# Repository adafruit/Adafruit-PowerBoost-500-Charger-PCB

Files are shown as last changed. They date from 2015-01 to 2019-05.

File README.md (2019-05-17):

# Adafruit PowerBoost 500 Charger PCB
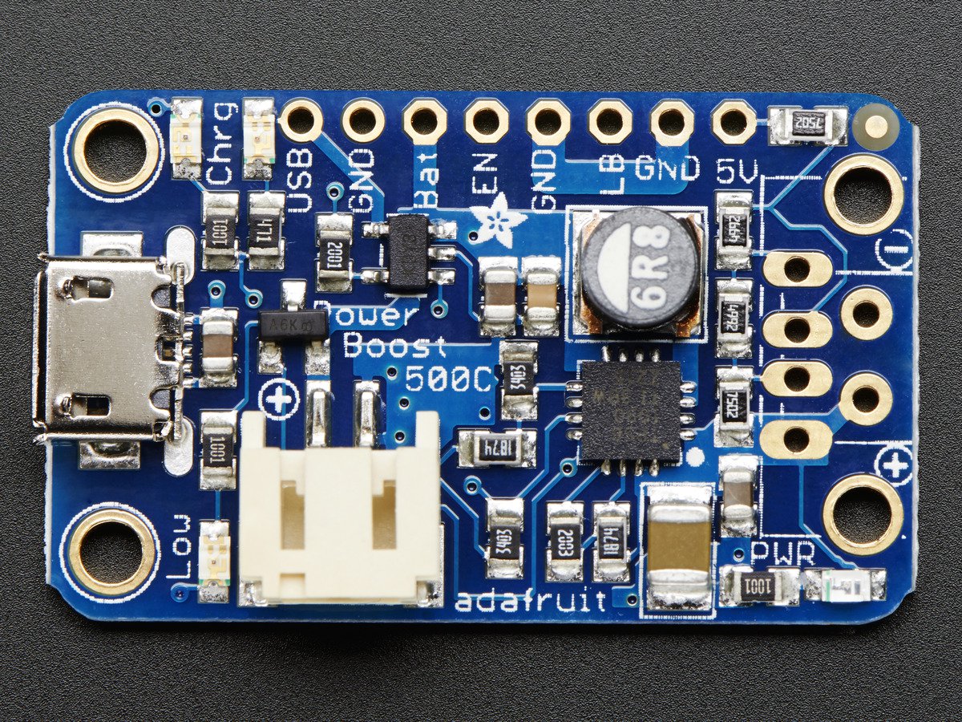
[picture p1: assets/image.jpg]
<a href="http://www.adafruit.com/products/1944"><br/>
Click here to purchase one from the Adafruit shop
</a>

The PowerBoost 500C is the perfect power supply for your portable project! With a built-in battery charger circuit, you'll be able to keep your project running even while recharging the battery! This little DC/DC boost converter module can be powered by any 3.7V LiIon/LiPoly battery, and convert the battery output to 5.2V DC for running your 5V projects.

Like our popular 5V 1A USB wall adapter, the output has been tweaked to be 5.2V instead of a straight-up 5.0V so that there's a little bit of 'headroom' for long cables, high draw, the addition of a diode on the output if you wish, etc. The 5.2V is safe for all 5V-powered electronics like Arduino, Adafruit Metro, Raspberry Pi, or BeagleBone while preventing icky brown-outs during high current draw because of USB cable resistance.

The PowerBoost 500C has at the heart a TPS61090 boost converter from TI. This boost converter chip has some really nice extras such as low battery detection, 2A internal switch, synchronous conversion, excellent efficiency, and 700KHz high-frequency operation.

This repo contains the PCB files for the Adafruit PowerBoost 500 Charger

### License

Adafruit invests time and resources providing this open source design, please support Adafruit and open-source hardware by purchasing products from [Adafruit](https://www.adafruit.com)!

All text above must be included in any redistribution

Designed by Limor Fried/Ladyada for Adafruit Industries.
Creative Commons Attribution/Share-Alike, all text above must be included in any redistribution. 
See license.txt for additional information.

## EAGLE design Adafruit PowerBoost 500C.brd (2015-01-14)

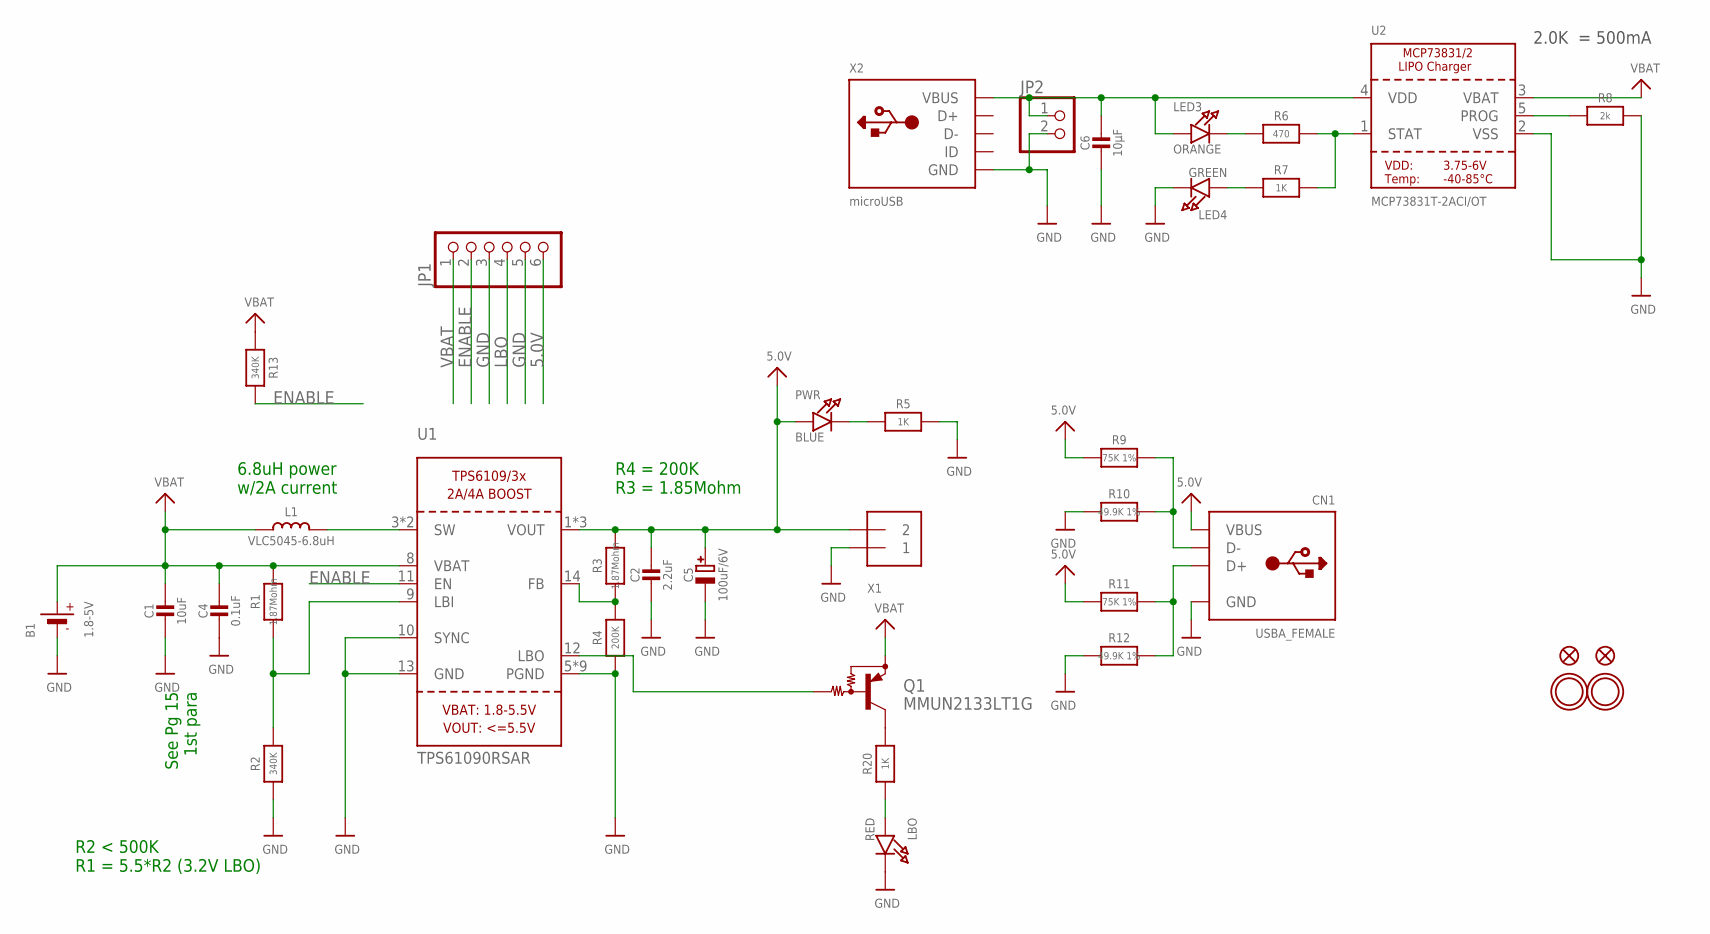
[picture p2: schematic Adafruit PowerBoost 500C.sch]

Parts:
B1: 1.8-5V; JSTPH2
C1: 10uF; 0805-NO
C2: 2.2uF; 0805-NO
C4: 0.1uF; 0805-NO
C5: 100uF/6V; EIA3528-21/B-R
C6: 10µF; 0805-NO
CN1: USBA_FEMALE; USB_HOST-PTH
FID2, FID3: FIDUCIAL""; FIDUCIAL_1MM
JP1: PINHD-1X6CB; 1X06-CLEANBIG
JP2: HEADER-1X2ROUND; 1X02_ROUND
L1: VLC5045-6.8uH; INDUCTOR_5X5MM_TDK_VLC5045
LBO: RED; CHIPLED_0805_NOOUTLINE
LED3: ORANGE; CHIPLED_0805_NOOUTLINE
LED4: GREEN; CHIPLED_0805_NOOUTLINE
PWR: BLUE; CHIPLED_0805_NOOUTLINE
Q1: MMUN2133LT1G; SC59-BEC
R1, R3: 1.87Mohm; 0805-NO
R2, R13: 340K; 0805-NO
R4: 200K; 0805-NO
R5, R7, R20: 1K; 0805-NO
R6: 470; 0805-NO
R8: 2k; 0805-NO
R9, R11: 75K 1%; 0805-NO
R10, R12: 49.9K 1%; 0805-NO
U1: TPS61090RSAR; PVQFN-16
U2: MCP73831T-2ACI/OT; SOT23-5
U$10, U$12: MOUNTINGHOLE2.5; MOUNTINGHOLE_2.5_PLATED
X1: TERMBLOCK_1X2; TERMBLOCK_1X2-3.5MM
X2: microUSB; 4UCONN_20329

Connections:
5.0V: C2.1, C5.+, CN1.VBUS, JP1.6, PWR.A, R3.2, R9.2, R11.2, U1.1 (VOUT), U1.15 (VOUT), U1.16 (VOUT), X1.2
D+: CN1.D+, R11.1, R12.1
D-: CN1.D-, R9.1, R10.1
ENABLE: JP1.2, R13.2, U1.11 (EN)
GND: B1.1 (-), C1.2, C2.2, C4.2, C5.-, C6.2, CN1.GND, JP1.3, JP1.5, JP2.2, LBO.C, LED4.C, R2.1, R4.1, R5.2, R8.2, R10.2, R12.2, U1.5 (PGND), U1.6 (PGND), U1.7 (PGND), U1.10 (SYNC), U1.13 (GND), U1.P$18 (PGND), U1.P$19 (PGND), U1.P$20 (PGND), U1.P$21 (PGND), U1.P$22 (PGND), U1.THERMAL (PGND), U2.2 (VSS), X1.1, X2.BASE@1 (GND), X2.BASE@2 (GND), X2.GND, X2.SPRT@1 (GND), X2.SPRT@2 (GND), X2.SPRT@3 (GND), X2.SPRT@4 (GND)
LBO: JP1.4, Q1.B, U1.12 (LBO)
unnamed: L1.P$2 (2), U1.3 (SW), U1.4 (SW)
unnamed: LBO.A, R20.1
unnamed: R1.1, R2.2, U1.9 (LBI)
unnamed: PWR.C, R5.1
unnamed: R3.1, R4.2, U1.14 (FB)
unnamed: LED3.C, R6.1
unnamed: R6.2, R7.2, U2.1 (STAT)
unnamed: R8.1, U2.5 (PROG)
unnamed: LED4.A, R7.1
unnamed: Q1.C, R20.2
VBAT: B1.2 (+), C1.1, C4.1, JP1.1, L1.P$1 (1), Q1.E, R1.2, R13.1, U1.8 (VBAT), U2.3 (VBAT)
VDD1: C6.1, JP2.1, LED3.A, U2.4 (VDD), X2.VBUS

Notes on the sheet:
See Pg 15 1st para
6.8uH power w/2A current
R2 < 500K R1 = 5.5*R2 (3.2V LBO)
R4 = 200K R3 = 1.85Mohm
2.0K = 500mA

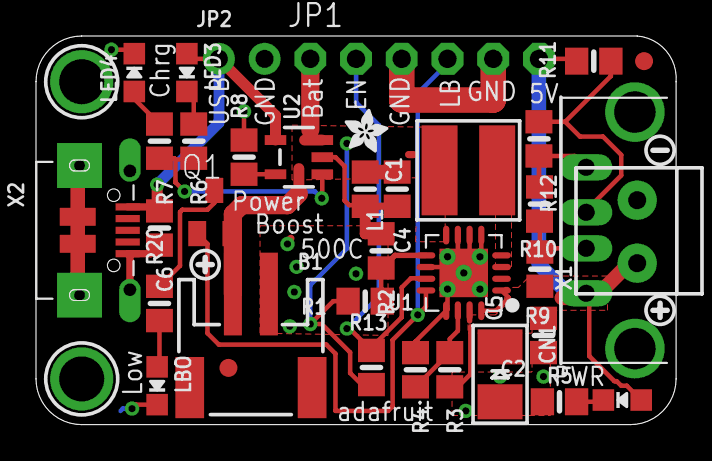
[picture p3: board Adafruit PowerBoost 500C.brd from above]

Board: 2 copper layers, 35.6 x 21.6 mm, 42 parts (1 on the bottom side), 18 nets.

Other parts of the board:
U$13, U$25: SYMBOL_PLUS
U$26: SYMBOL_MINUS
U$28: ADAFRUIT_2.5MM
U$29: ADAFRUIT_5MM

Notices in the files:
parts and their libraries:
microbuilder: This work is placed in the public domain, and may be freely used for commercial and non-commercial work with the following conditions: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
